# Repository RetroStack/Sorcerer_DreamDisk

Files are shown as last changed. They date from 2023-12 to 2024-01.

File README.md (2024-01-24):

# Exidy Sorcerer DreamDisk - Disk Controller

A Disk Controller for the Exidy Sorcerer, based on the Disk Controller by DreamCards.

Requires SCUAMON3.4 Monitor ROMS with Dreamdisk FDC support installed in Sorcerer for Cold Booting Dreamdisk.

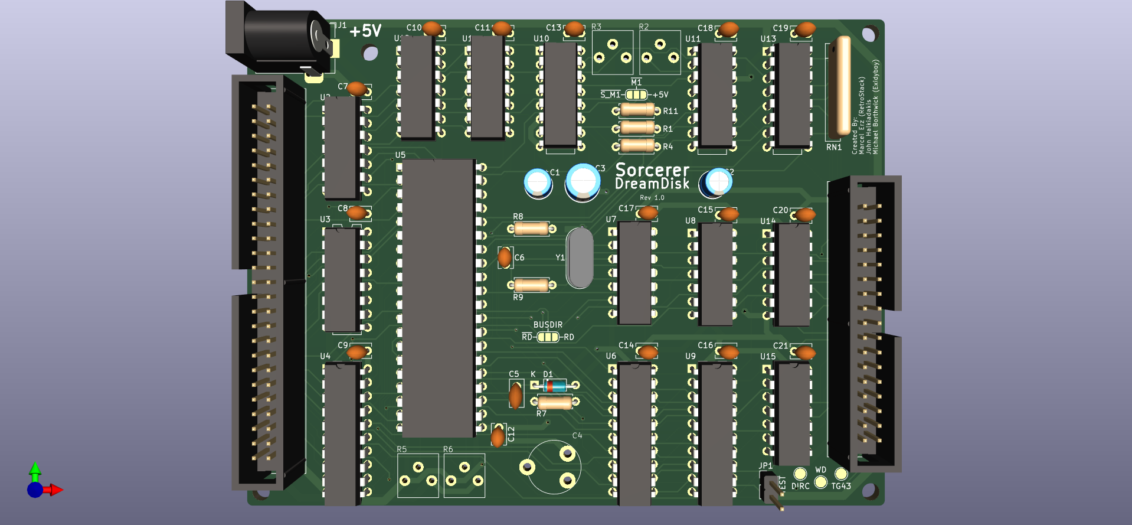
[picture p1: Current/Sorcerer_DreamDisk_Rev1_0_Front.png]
Sorcerer DreamDisk Front

[Schematics](Current/Sorcerer_DreamDisk_Rev1_0_Schematics.pdf)

## Gerber Files
- [PCBWay](Current/Sorcerer_DreamDisk_Rev1_0_Gerber_PCBWay.zip)
- [JLCPCB](Current/Sorcerer_DreamDisk_Rev1_0_Gerber_JLCPCB.zip)

## Attribution
- Marcel Erz (RetroStack)
- John Halkiadakis
- Michael Borthwick (Exidyboy)

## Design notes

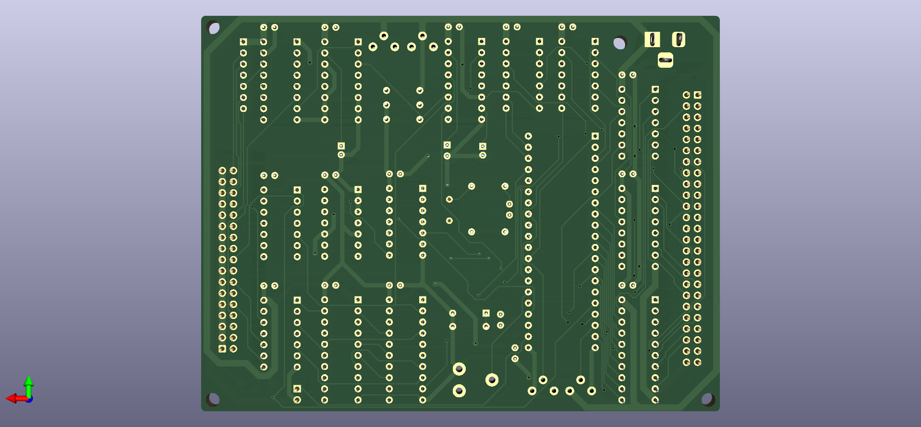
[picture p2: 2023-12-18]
Current/Sorcerer_DreamDisk_Rev1_0_Back.png

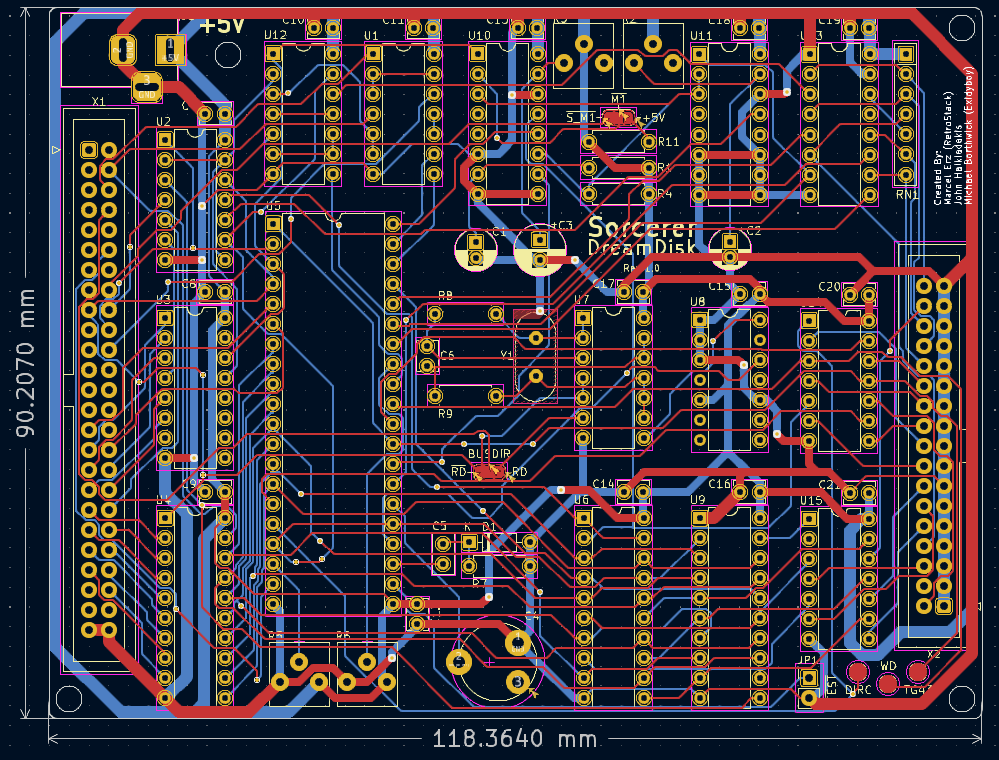
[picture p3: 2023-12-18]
Current/Sorcerer_DreamDisk_Rev1_0_PCB.png

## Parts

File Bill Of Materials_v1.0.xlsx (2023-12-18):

Mouser No | Mfr. No | Manufacturer | PCB Layout | Description | Order Qty. | Price (AUD) | Ext.: (AUD)
810-FG14X7R1H224KNT0 | FG14X7R1H224KNT00 | TDK | C5 | Multilayer Ceramic Capacitors MLCC - Leaded RAD 50V 0.22uF X7R 10% LS:2.5mm | 1 | $0.47 | $0.47
594-K104K10X7RF53H5 | K104K10X7RF53H5 | Vishay | C6, C8-C21 | Multilayer Ceramic Capacitors MLCC - Leaded 0.1uF 50V 10% X7R 5mm LS | 16 | $0.167 | $2.67
603-MFR-25FBF52-4K7 | MFR-25FBF52-4K7 | YAGEO | R11 | Metal Film Resistors - Through Hole 4.7K OHM 1/4W 1% | 1 | $0.162 | $0.16
603-MFR-25FRF52-470R | MFR-25FRF52-470R | YAGEO | R8, R9 | Metal Film Resistors - Through Hole 470 OHM 1/4W 1% | 2 | $0.162 | $0.32
603-MFR-25FRE52-1K | MFR-25FRE52-1K | YAGEO | R1, R7 | Metal Film Resistors - Through Hole 1Kohm 1% 1/4W Metal Film Resistor | 2 | $0.162 | $0.32
603-MFR-25FRF5210K | MFR-25FRF52-10K | YAGEO | R4 | Metal Film Resistors - Through Hole 10 kOhms 250 mW 1% 100 PPM / C | 1 | $0.162 | $0.16
652-4607X-1LF-4.7K | 4607X-101-472LF | Bourns | RN1 | Resistor Networks & Arrays 7pins 4.7Kohms Bussed | 1 | $0.81 | $0.81
595-SN74LS02N | SN74LS02N | Texas Instruments | U1 | Logic Gates Quad 2-Input | 1 | $0.891 | $0.89
595-SN74LS32N | SN74LS32N | Texas Instruments | U2 | Logic Gates Quad 2-Input | 1 | $0.907 | $0.91
595-SN74LS138N | SN74LS138N | Texas Instruments | U3 | Encoders, Decoders, Multiplexers & Demultiplexers Line Decoder | 1 | $1.13 | $1.13
595-SN74LS245N | SN74LS245N | Texas Instruments | U4 | Bus Transceivers Octal Bus | 1 | $2.01 | $2.01
595-SN74LS244N | SN74LS244N | Texas Instruments | U6 | Buffers & Line Drivers Tri-State Octal | 1 | $1.88 | $1.88
595-SN74LS00N | SN74LS00N | Texas Instruments | U7, U12 | Logic Gates Quad 2-In Pos NAND | 2 | $0.923 | $1.85
512-1N914TR | 1N914TR | onsemi | D1 | Diodes - General Purpose, Power, Switching Hi Conductance Fast | 1 | $0.162 | $0.16
649-67998-400HLF | 67998-400HLF | Amphenol | JP1 TEST | Headers & Wire Housings .100CC STR HEADER | 1 | $0.162 | $0.16
710-860020672005 | 860020672005 | Wurth Elektronik | C1 | Aluminium Electrolytic Capacitors - Radial Leaded WCAP-ATG5 1uF 50V 20% Radial | 1 | $0.162 | $0.16
710-860020472006 | 860020472006 | Wurth Elektronik | C2 | Aluminium Electrolytic Capacitors - Radial Leaded WCAP-ATG5 47uF 25V 20% Radial | 1 | $0.162 | $0.16
710-860010273009 | 860010273009 | Wurth Elektronik | C3 | Aluminium Electrolytic Capacitors - Radial Leaded WCAP-ATG8 220uF 10V 20% Radial | 1 | $0.243 | $0.24
595-SN74LS374N | SN74LS374N | Texas Instruments | U9 | Flip-Flops Octal | 1 | $2.01 | $2.01
595-SN74LS123N | SN74LS123N | Texas Instruments | U10, U11 | Monostable Multi-vibrator Dual Mono | 2 | $1.30 | $2.60
595-SN74LS367AN | SN74LS367AN | Texas Instruments | U13 | Buffers & Line Drivers Hex Bus Drivers With 3-State Outputs | 1 | $2.33 | $2.33
595-SN74LS06N | SN74LS06N | Texas Instruments | U14 | Buffers & Line Drivers Hex inverter Buffer/ Driver | 1 | $1.49 | $1.49
571-5103308-7 | 5103308-7 | TE Connectivity | X2 | Headers & Wire Housings 34P HEADER | 1 | $6.04 | $6.04
571-1-5103308-0 | 1-5103308-0 | TE Connectivity | X1 | Headers & Wire Housings 50P HEADER SP 15DP | 1 | $6.66 | $6.66
652-3306P-1-503 | 3306P-1-503 | Bourns | R2 ,R5 | Trimmer Resistors - Through Hole 50K 25% 6mm Single Turn | 2 | $0.713 | $1.43
652-3306P-1-502 | 3306P-1-502 | Bourns | R6 (ONLY for 8") | Trimmer Resistors - Through Hole 5K 25% 6mm Single Turn | 1 | $0.761 | $0.76
652-3306P-1-104 | 3306P-1-104 | Bourns | R3 | Trimmer Resistors - Through Hole 100K 25% 6mm Single Turn | 1 | $0.794 | $0.79
73-XT49S400-20 | XT9S20ANA4M | Vishay | Y1 | Crystals 4MHz 20pF | 1 | $0.778 | $0.78
474-PRT-10811 | PRT-10811 | SparkFun Electronics | J1 | SparkFun Accessories DC Barrel Jack Adapter - Breadboard Compatible | 1 | $1.54 | $1.54
595-SN74LS07N | SN74LS07N | Texas Instruments | U15 | Buffers & Line Drivers Hex W/ OC HV Out | 1 | $1.15 | $1.15
594-2222-808-32659 | BFC280832659 | Vishay | C4 (VCO ADJ) | Trimmer/Variable Capacitors TRIMMER CAPACITOR (5.5 pF to 65 pF) | 1 | $9.98 | $9.98
595-SN74LS93N | SN74LS93N | Texas Instruments | U8 | Counter ICs 4bit Binary | 1 | $4.92 | $4.92
WD2793 | N/A | N/A | U5 | Western Digital 2793 Floppy Disk Controller

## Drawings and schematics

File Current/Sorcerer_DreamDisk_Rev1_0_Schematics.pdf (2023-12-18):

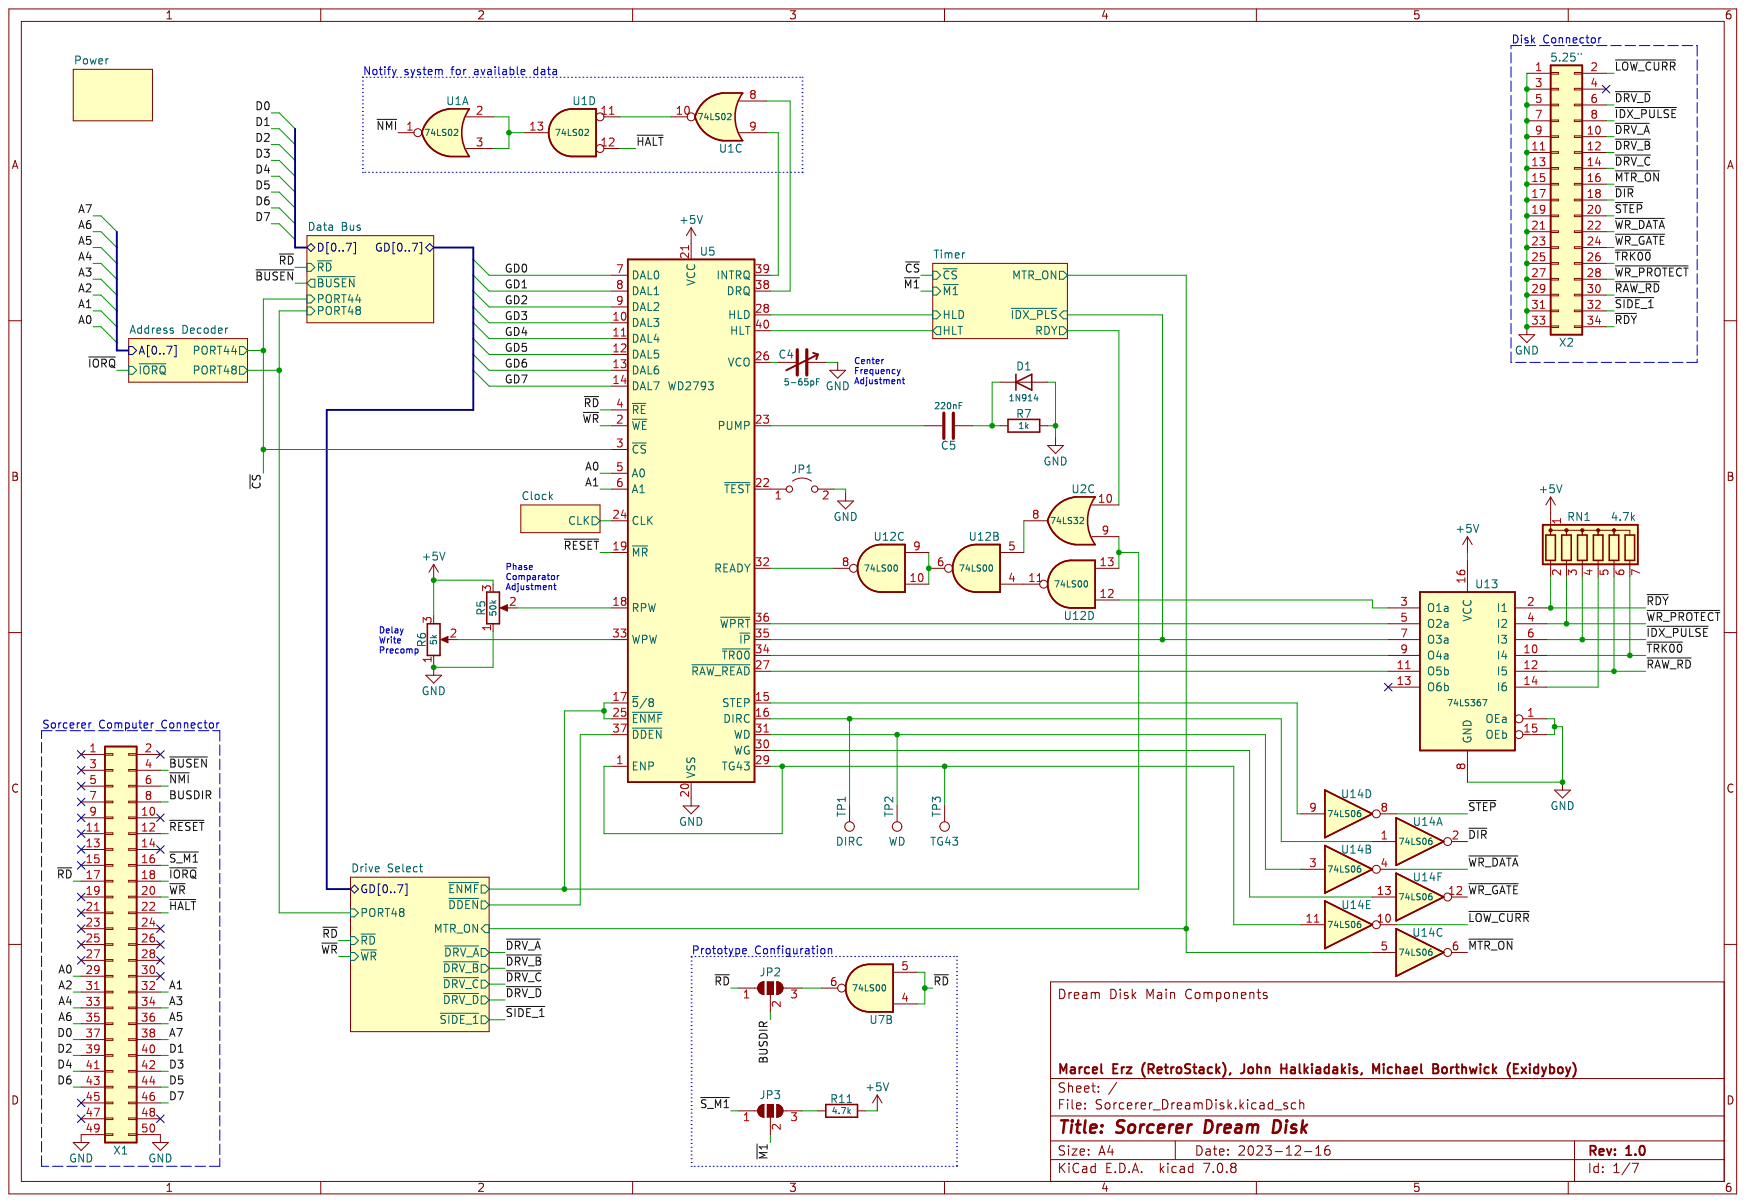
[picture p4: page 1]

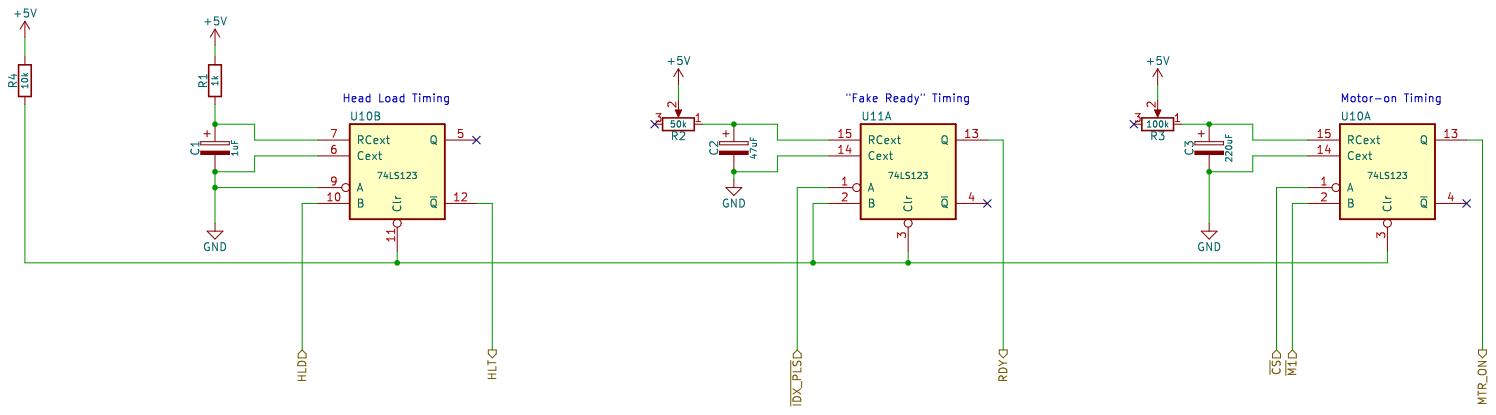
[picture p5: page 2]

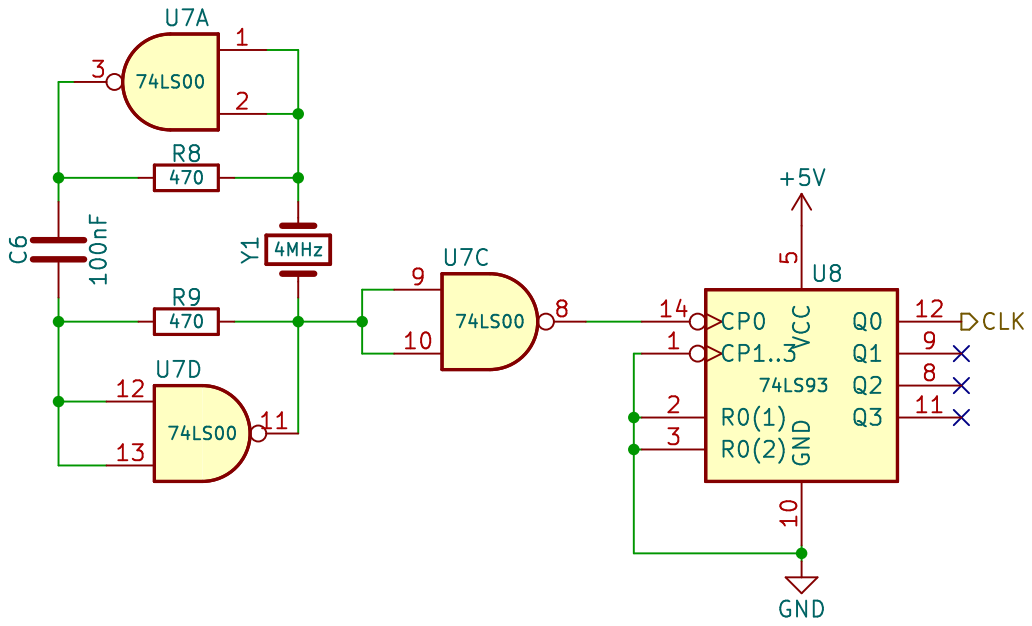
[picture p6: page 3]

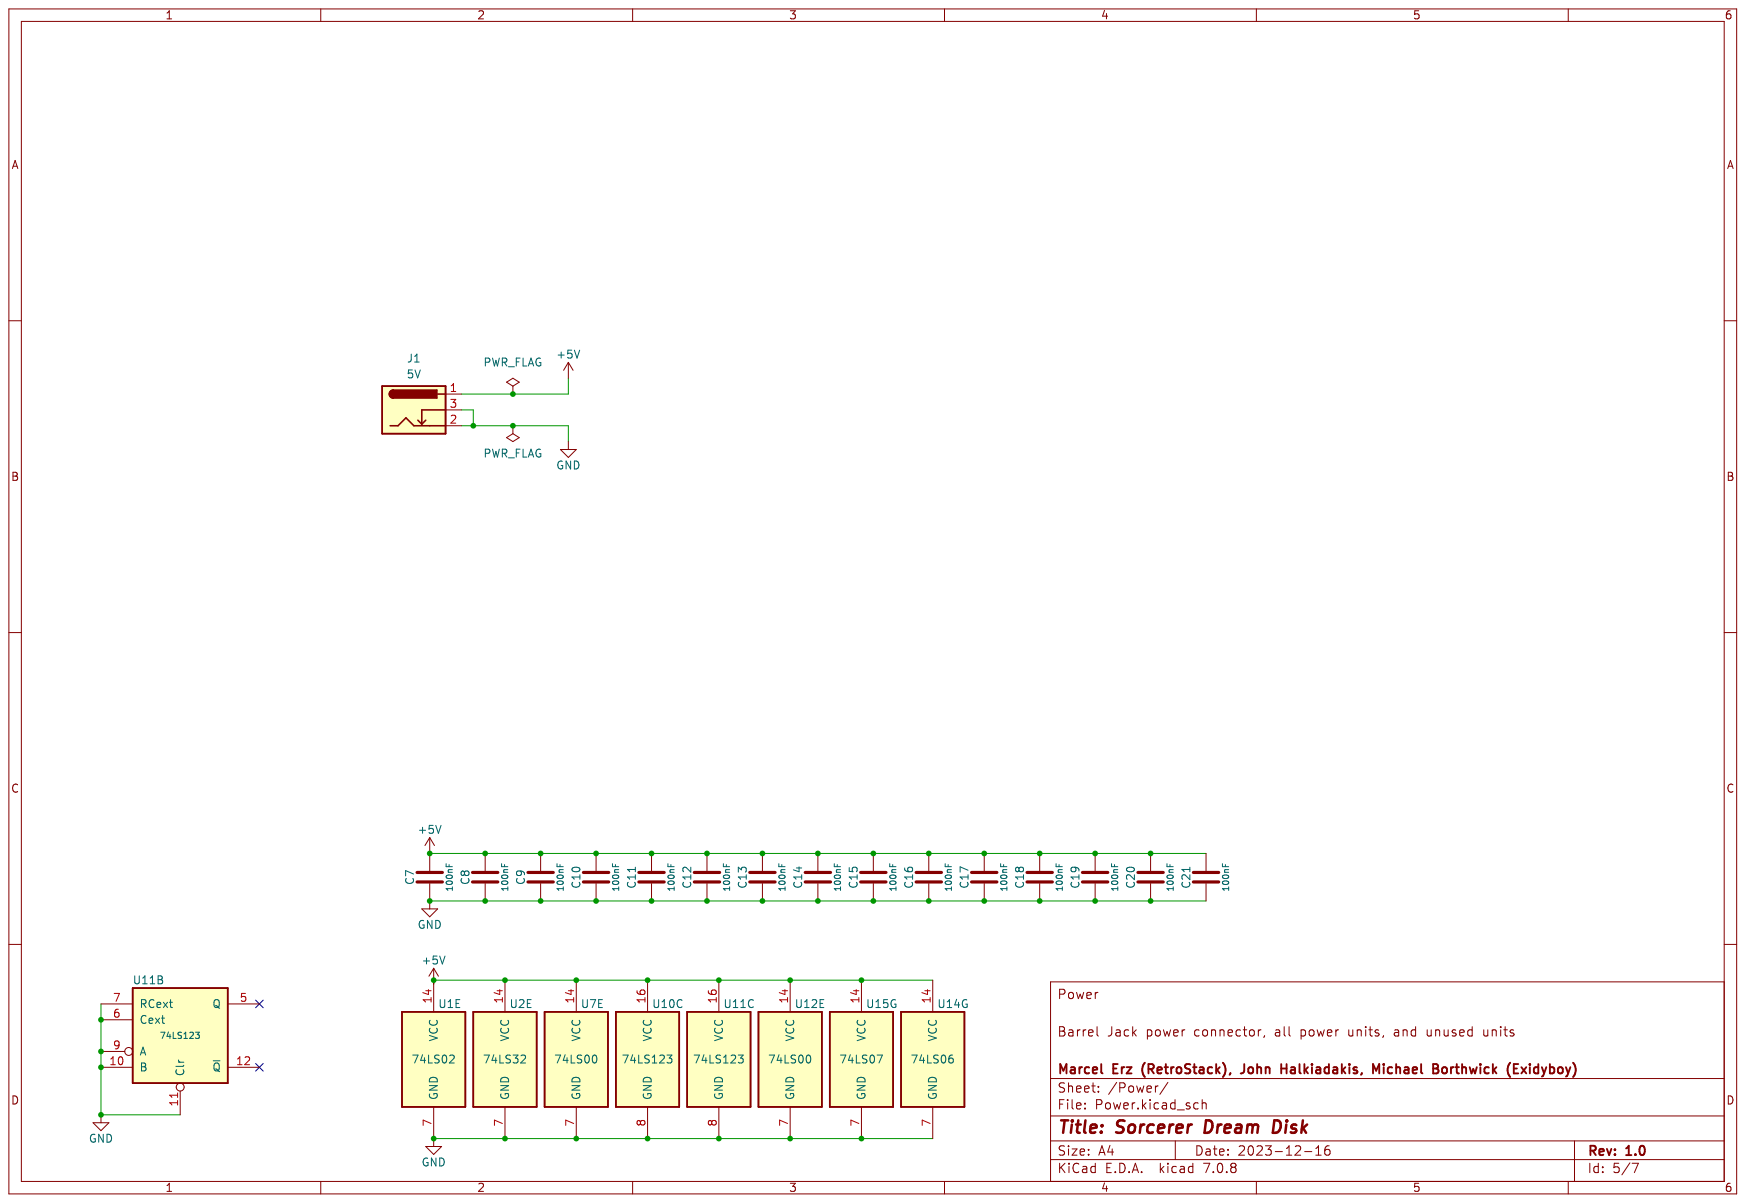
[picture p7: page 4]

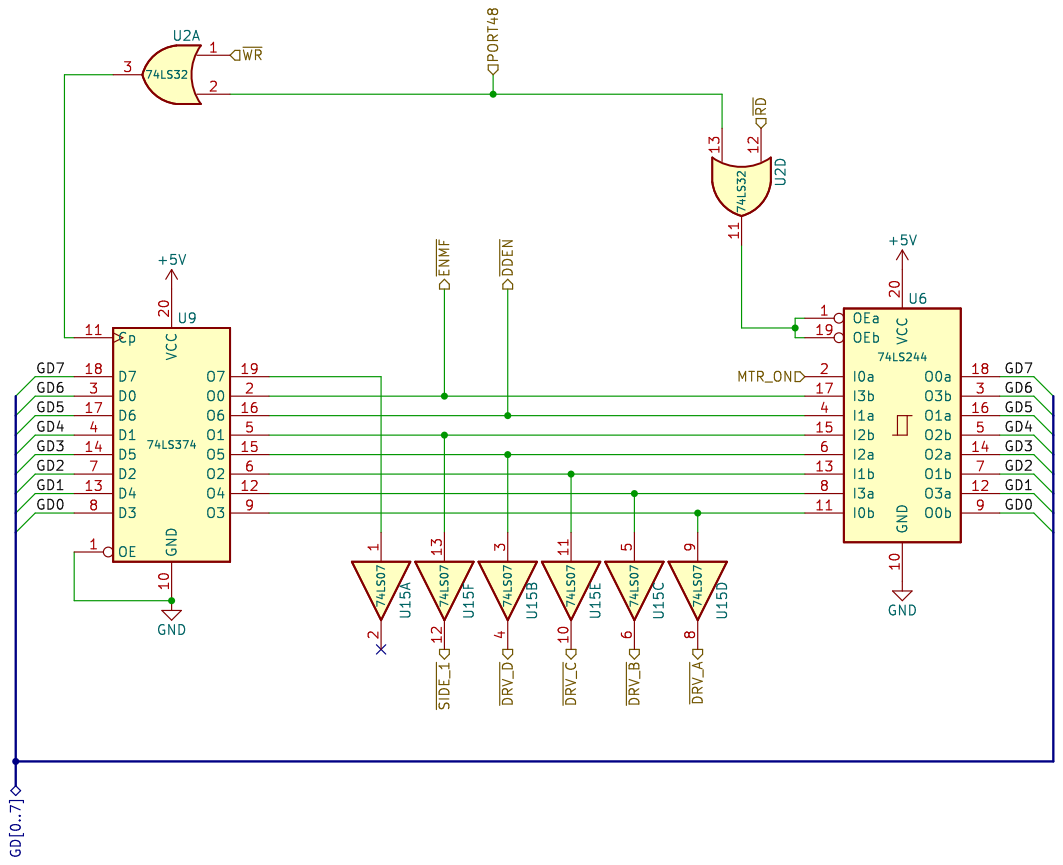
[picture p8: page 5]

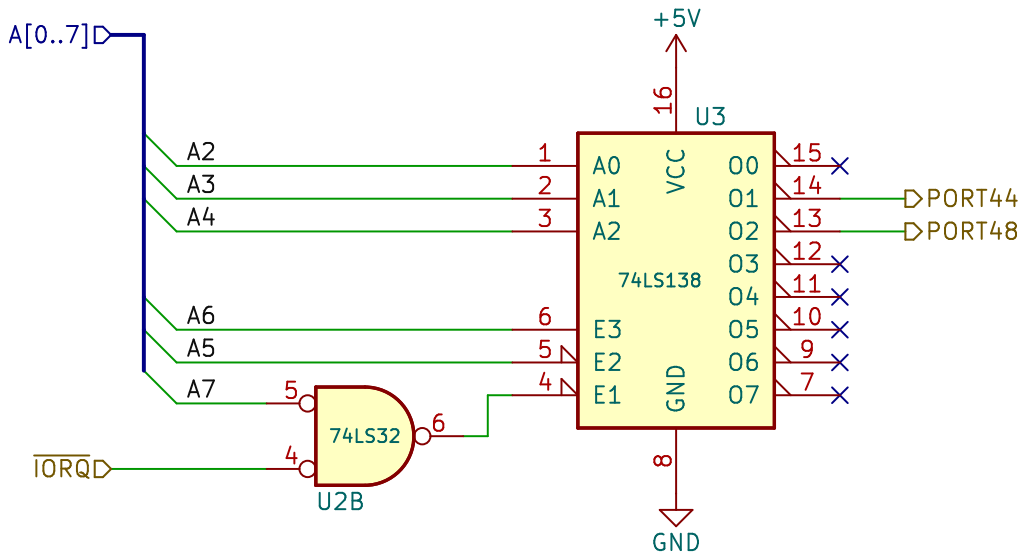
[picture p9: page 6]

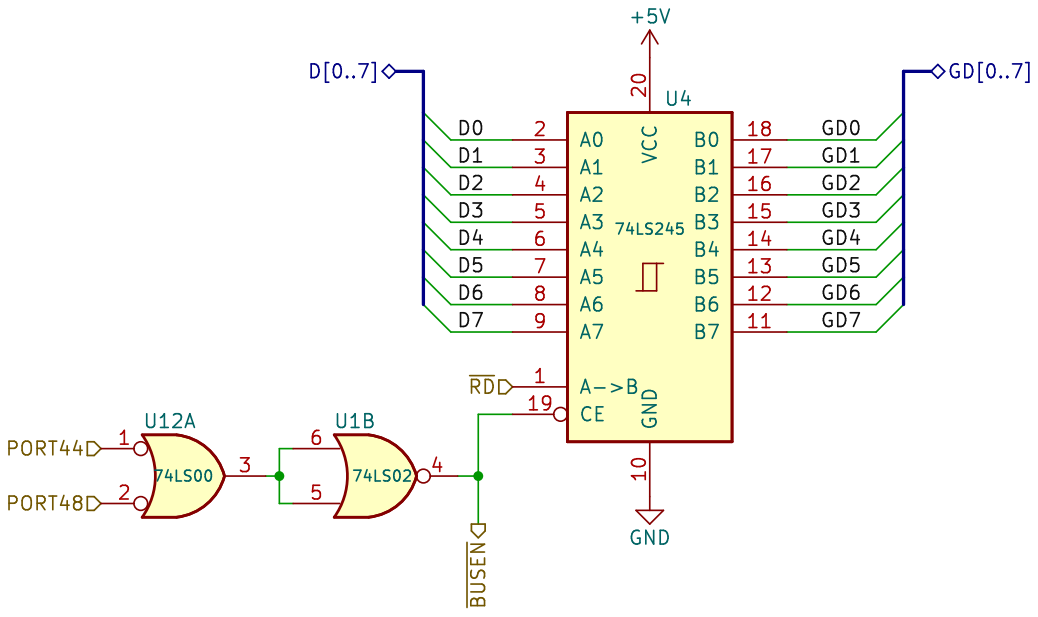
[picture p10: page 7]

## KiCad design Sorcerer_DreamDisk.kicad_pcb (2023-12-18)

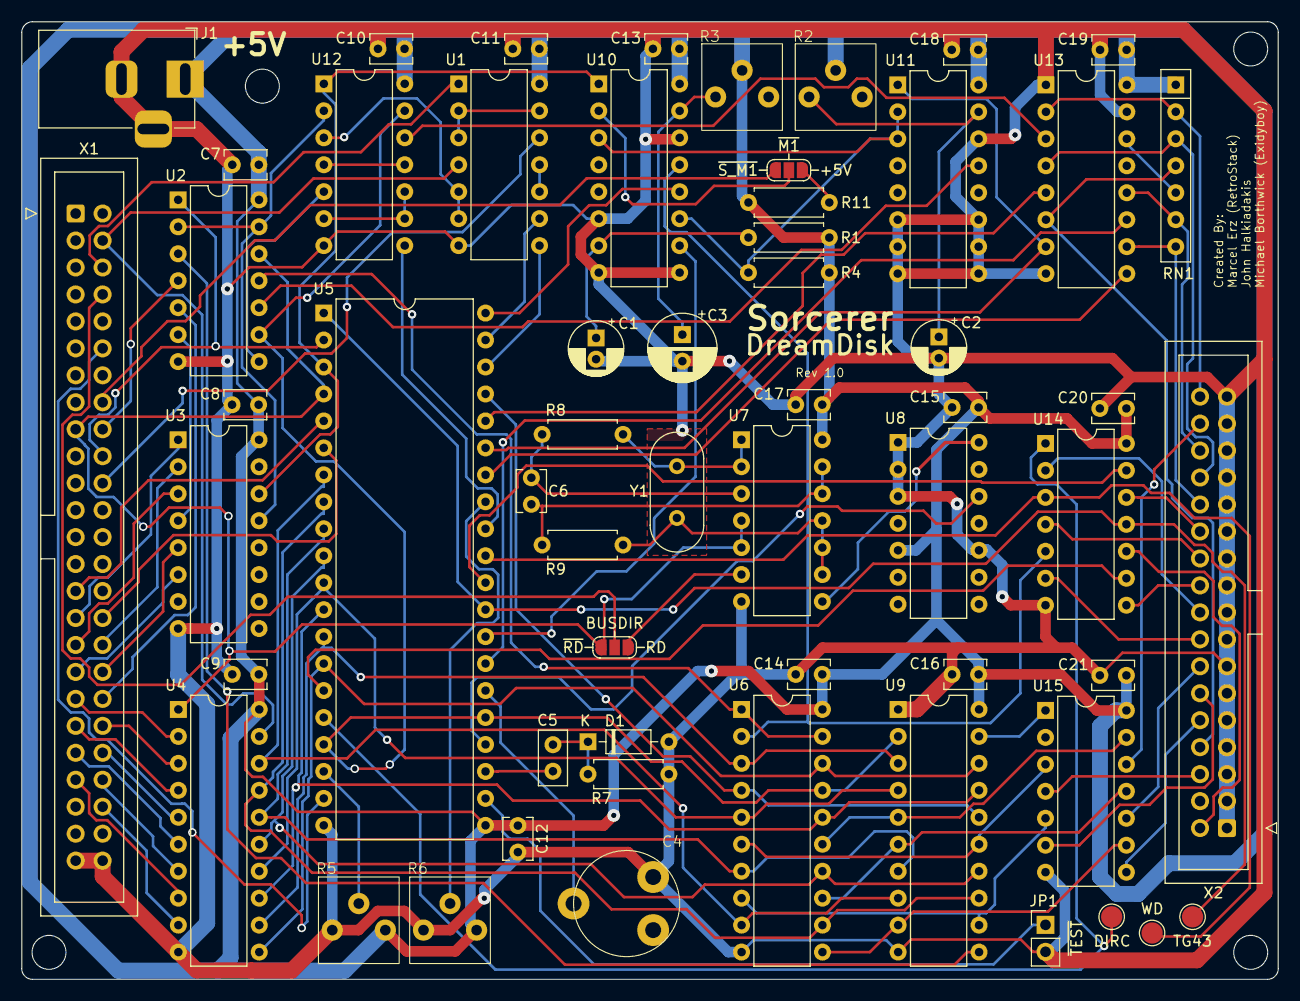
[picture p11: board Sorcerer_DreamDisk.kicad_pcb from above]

Board: 2 copper layers, 118.4 x 90.2 mm, 58 parts (0 on the bottom side), 107 nets.

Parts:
C1: 1uF; CP_Radial_D5.0mm_P2.00mm
C2: 47uF; CP_Radial_D5.0mm_P2.00mm
C3: 220uF; CP_Radial_D6.3mm_P2.50mm
C4: 5-65pF; C_Trim (BFC2 808 32659)
C5: 220nF; C_Disc_D5.0mm_W2.5mm_P2.50mm
C6, C7, C8, C9, C10, C11, C12, C13, C14, C15, C16, C17, C18, C19, C20, C21: 100nF; C_Disc_D3.8mm_W2.6mm_P2.50mm
D1: 1N914; D_DO-35_SOD27_P7.62mm_Horizontal
J1: 5V; BarrelJack_Horizontal
JP1: Jumper_2_Open; PinHeader_1x02_P2.54mm_Vertical
JP2, JP3: SolderJumper_3_Open; SolderJumper-3_P1.3mm_Open_RoundedPad1.0x1.5mm_NumberLabels
R1, R7: 1k; R_Axial_DIN0207_L6.3mm_D2.5mm_P7.62mm_Horizontal
R2, R5: 50k; R_Pot (Bourns 3306P)
R3: 100k; R_Pot (Bourns 3306P)
R4: 10k; R_Axial_DIN0207_L6.3mm_D2.5mm_P7.62mm_Horizontal
R6: 5k; R_Pot (Bourns 3306P)
R8, R9: 470; R_Axial_DIN0207_L6.3mm_D2.5mm_P7.62mm_Horizontal
R11: 4.7k; R_Axial_DIN0207_L6.3mm_D2.5mm_P7.62mm_Horizontal
RN1: 4.7k; R_Array_SIP7
TP1: DIRC; TestPoint_Pad_D2.0mm
TP2: WD; TestPoint_Pad_D2.0mm
TP3: TG43; TestPoint_Pad_D2.0mm
U1: 74LS02; DIP-14_W7.62mm
U2: 74LS32; DIP-14_W7.62mm
U3: 74LS138; DIP-16_W7.62mm
U4: 74LS245; DIP-20_W7.62mm
U5: WD2793; DIP-40_W15.24mm
U6: 74LS244; DIP-20_W7.62mm
U7, U12: 74LS00; DIP-14_W7.62mm
U8: 74LS93; DIP-14_W7.62mm
U9: 74LS374; DIP-20_W7.62mm
U10, U11: 74LS123; DIP-16_W7.62mm
U13: 74LS367; DIP-16_W7.62mm
U14: 74LS06; DIP-14_W7.62mm
U15: 74LS07; DIP-14_W7.62mm
X1: To_Computer; IDC-Header_2x25_P2.54mm_Vertical
X2: 5.25"; IDC-Header_2x17_P2.54mm_Vertical
Y1: 4MHz; Crystal_HC49-U_Vertical

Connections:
+5V: C7.2, C8.2, C9.2, C10.2, C11.2, C12.2, C13.2, C14.2, C15.2, C16.2, C17.2, C18.2, C19.2, C20.2, C21.2, J1.1, R1.1, R2.2, R3.2, R4.1, R5.3, R6.3, R11.1, RN1.1 (common), U1.14 (VCC), U2.14 (VCC), U3.16 (VCC), U4.20 (VCC), U5.21 (VCC), U6.20 (VCC), U7.14 (VCC), U8.5 (VCC), U9.20 (VCC), U10.16 (VCC), U11.16 (VCC), U12.14 (VCC), U13.16 (VCC), U14.14 (VCC), U15.14 (VCC)
/Address Decoder/A0: U5.5 (A0), X1.29
/Address Decoder/A1: U5.6 (A1), X1.32
/Address Decoder/A2: U3.1 (A0), X1.31
/Address Decoder/A3: U3.2 (A1), X1.34
/Address Decoder/A4: U3.3 (A2), X1.33
/Address Decoder/A5: U3.5 (E2), X1.36
/Address Decoder/A6: U3.6 (E3), X1.35
/Address Decoder/A7: U2.5, X1.38
/Address Decoder/PORT48: U2.2, U2.13, U3.13 (O2), U12.2
/BUSDIR: JP2.2 (C), X1.8
/Clock/CLK: U5.24 (CLK), U8.12 (Q0)
/Data Bus/D0: U4.2 (A0), X1.37
/Data Bus/D1: U4.3 (A1), X1.40
/Data Bus/D2: U4.4 (A2), X1.39
/Data Bus/D3: U4.5 (A3), X1.42
/Data Bus/D4: U4.6 (A4), X1.41
/Data Bus/D5: U4.7 (A5), X1.44
/Data Bus/D6: U4.8 (A6), X1.43
/Data Bus/D7: U4.9 (A7), X1.46
/Data Bus/GD0: U4.18 (B0), U5.7 (DAL0), U6.9 (O0b), U9.8 (D3)
/Data Bus/GD1: U4.17 (B1), U5.8 (DAL1), U6.12 (O3a), U9.13 (D4)
/Data Bus/GD2: U4.16 (B2), U5.9 (DAL2), U6.7 (O1b), U9.7 (D2)
/Data Bus/GD3: U4.15 (B3), U5.10 (DAL3), U6.14 (O2a), U9.14 (D5)
/Data Bus/GD4: U4.14 (B4), U5.11 (DAL4), U6.5 (O2b), U9.4 (D1)
/Data Bus/GD5: U4.13 (B5), U5.12 (DAL5), U6.16 (O1a), U9.17 (D6)
/Data Bus/GD6: U4.12 (B6), U5.13 (DAL6), U6.3 (O3b), U9.3 (D0)
/Data Bus/GD7: U4.11 (B7), U5.14 (DAL7), U6.18 (O0a), U9.18 (D7)
/Drive Select/MTR_ON: U6.2 (I0a), U10.13 (Q), U14.5
/Drive Select/~DDEN: U5.37 (~DDEN), U6.4 (I1a), U9.16 (O6)
/Drive Select/~ENMF: U2.9, U5.17 (~5/8), U5.25 (~ENMF), U6.17 (I3b), U9.2 (O0), U12.13
/Timer/HLD: U5.28 (HLD), U10.10 (B)
/Timer/HLT: U5.40 (HLT), U10.12 (~Q)
/Timer/RDY: U2.10, U11.13 (Q)
/Timer/~IDX_PLS: U5.35 (~IP), U11.1 (A), U13.7 (O3a)
/~BUSEN: U1.4, U4.19 (CE), X1.4
/~CS: U3.14 (O1), U5.3 (~CS), U10.1 (A), U12.1
/~DIR: U14.2, X2.18
/~DRV_A: U15.8, X2.10
/~DRV_B: U15.6, X2.12
/~DRV_C: U15.10, X2.14
/~DRV_D: U15.4, X2.6
/~HALT: U1.12, X1.22
/~IDX_PULSE: RN1.4 (R3), U13.6 (I3), X2.8
/~IORQ: U2.4, X1.18
/~LOW_CURR: U14.10, X2.2
/~M1: JP3.2 (C), U10.2 (B)
/~MTR_ON: U14.6, X2.16
/~NMI: U1.1, X1.6
/~RAW_RD: RN1.6 (R5), U13.12 (I5), X2.30
/~RDY: RN1.2 (R1), U13.2 (I1), X2.34
/~RD: JP2.1 (A), U2.12, U4.1 (A->B), U5.4 (~RE), U7.4, U7.5, X1.17
/~RESET: U5.19 (~MR), X1.12
/~SIDE_1: U15.12, X2.32
/~STEP: U14.8, X2.20
/~S_M1: JP3.1 (A), X1.16
/~TRK00: RN1.7 (R6), U13.10 (I4), X2.26
/~WR_DATA: U14.4, X2.22
/~WR_GATE: U14.12, X2.24
/~WR_PROTECT: RN1.3 (R2), U13.4 (I2), X2.28
/~WR: U2.1, U5.2 (~WE), X1.20
GND: C1.2, C2.2, C3.2, C4.1, C7.1, C8.1, C9.1, C10.1, C11.1, C12.1, C13.1, C14.1, C15.1, C16.1, C17.1, C18.1, C19.1, C20.1, C21.1, D1.2 (A), J1.2, J1.3, JP1.2 (B), R5.1, R6.1, R7.2, U1.7 (GND), U2.7 (GND), U3.8 (GND), U4.10 (GND), U5.20 (VSS), U6.10 (GND), U7.7 (GND), U8.1 (CP1..3), U8.2 (R0(1)), U8.3 (R0(2)), U8.10 (GND), U9.1 (OE), U9.10 (GND), U10.6 (Cext), U10.8 (GND), U10.9 (A), U10.14 (Cext), U11.6 (Cext), U11.7 (RCext), U11.8 (GND), U11.9 (A), U11.10 (B), U11.11 (Clr), U11.14 (Cext), U12.7 (GND), U13.1 (OEa), U13.8 (GND), U13.15 (OEb), U14.7 (GND), U15.7 (GND), X1.49, X1.50, X2.1, X2.3, X2.5, X2.7, X2.9, X2.11, X2.13, X2.15, X2.17, X2.19, X2.21, X2.23, X2.25, X2.27, X2.29, X2.31, X2.33
unnamed: C6.1, R8.2, U7.3
unnamed: C6.2, R9.2, U7.12, U7.13
unnamed: C5.2, D1.1 (K), R7.1
unnamed: JP1.1 (A), U5.22 (~TEST)
unnamed: JP2.3 (B), U7.6
unnamed: JP3.3 (B), R11.2
unnamed: R8.1, U7.1, U7.2, Y1.2
unnamed: R9.1, U7.9, U7.10, U7.11, Y1.1
unnamed: RN1.5 (R4), U13.14 (I6)
unnamed: U1.5, U1.6, U12.3
unnamed: U1.10, U1.11
unnamed: U1.2, U1.3, U1.13
unnamed: U2.6, U3.4 (E1)
unnamed: TP1.1, U5.16 (DIRC), U14.1
unnamed: U1.8, U5.38 (DRQ)
unnamed: TP3.1, U5.1 (ENP), U5.29 (TG43), U14.11
unnamed: U1.9, U5.39 (INTRQ)
unnamed: C5.1, U5.23 (PUMP)
unnamed: U5.32 (READY), U12.8
unnamed: R5.2, U5.18 (RPW)
unnamed: U5.15 (STEP), U14.9
unnamed: C4.2, U5.26 (VCO)
unnamed: TP2.1, U5.31 (WD), U14.3
unnamed: U5.30 (WG), U14.13
unnamed: R6.2, U5.33 (WPW)
unnamed: U6.11 (I0b), U9.9 (O3), U15.9
unnamed: U6.13 (I1b), U9.6 (O2), U15.11
unnamed: U6.6 (I2a), U9.15 (O5), U15.3
unnamed: U6.15 (I2b), U9.5 (O1), U15.13
unnamed: U6.8 (I3a), U9.12 (O4), U15.5
unnamed: U2.11, U6.1 (OEa), U6.19 (OEb)
unnamed: U7.8, U8.14 (CP0)
unnamed: U2.3, U9.11 (Cp)
unnamed: U9.19 (O7), U15.1
unnamed: R4.2, U10.3 (Clr), U10.11 (Clr), U11.2 (B), U11.3 (Clr)
unnamed: C3.1, R3.1, U10.15 (RCext)
unnamed: C1.1, R1.2, U10.7 (RCext)
unnamed: C2.1, R2.1, U11.15 (RCext)
unnamed: U2.8, U12.5
unnamed: U12.6, U12.9, U12.10
unnamed: U12.4, U12.11
unnamed: U12.12, U13.3 (O1a)
unnamed: U5.36 (~WPRT), U13.5 (O2a)
unnamed: U5.34 (~TR00), U13.9 (O4a)
unnamed: U5.27 (~RAW_READ), U13.11 (O5b)

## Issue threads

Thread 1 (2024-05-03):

Dream disc for Microbee with 8" drive support

pocoaust, 2024-05-03:
G'day,

I was going through the process of trying to recreate the dreamdisk for microbee when I came across your Project.  Would it be as simple as changing the 50 way interface wiring to get it to work with the bee, and adding the 50 pin 8" interface?  Looking at the RM001 schematics you have added BusDir and BusEn...    is this from the later version?

Did you also manage to actually get a real original Board?

Thanks
Paul

vk3yp, 2024-10-27:
Hi Paul,

The Dreamdisk FDC is based on the RM001 per the schematics from the original manual. We don't have an original RM001 FDC board - so everything was reverse engineered from the schematics only.

The circuit was modified for Sorcerer 50 PIN BUS pinout (i.e. not requiring the external original dreamdisk adapter PCB for the Sorcerer).

If you build an external PCB of your own design, you can remap the 50 PIN BUS pinouts back to Microbee. The bus pinout mapping is described in the original Dreamdisk Sorcerer manual.

We deleted the 8" disk drive header from the PCB to simplify and have only a 5.25" drive interface.
We also added the Busdir and BusEn pcb jumpers for testing and these can be removed from a future revision PCB.

Have a look at the files at the exidy sorcerer forums on how to setup and test the PCB including the jumpers.

https://www.exidysorcerer.net/
https://filebrowser.exidysorcerer.net/

Without any changes to the current PCB - You can add external PCB (your design) to remap the 50 way bus signals back to Microbee and also you can use one of the many commercially available (pre-built) 8" to 5.25" PCB adapters.
Like this one.
https://texelec.com/product/8-inch-floppy-adapter/

We hope to have an updated Dreamdisk PCB with both Sorcerer and Microbee 50 way bus headers on the same PCB (and some minor updates such as removing the Busdir and BusEn jumpers). @marcelerz

John

pocoaust, 2024-10-27:
Thanks for keeping me informed....

I have a microbee, but not a sorcerer, I will try to find one as well.

Thanks

On Sun, 27 Oct 2024, 8:40 pm John Halkiadakis, ***@***.***>
wrote:

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

marcelerz, 2025-05-12:
A new version was just released that does support the MicroBee now. However, we still don't have a 8" disk support.

vk3yp, 2025-05-12:
8" Floppy support can be supported via an 8" 50 way to 5.25" 34 way adapter board.
Like this one:
https://texelec.com/product/8-inch-floppy-adapter/

Closed 2025-05-12.

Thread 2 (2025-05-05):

2Mhz Clock Circuit Fix (Clean 2Mhz Clock signal)

vk3yp, 2025-05-05:
This fix provides a clean 2Mhz clock signal to the CLK input (PIN 24) of the WD2793.

-	You need to add a 470PF (ceramic disc capacitor) between PIN 14 (CLK A INPUT) and PIN 1 (GND) ON IC U8 (74LS93) on the bottom of the PCB or you can add it to the legs of the 74LS93 IC (from the top of the PCB).

Photo image shows a 0603 package (470PF Surface Mount Capacitor) but a normal 470PF disk ceramic capacitor is fine.

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

marcelerz, 2025-05-12:
To clarify, this is for Rev 1.0 only. Rev 1.1 has this already fixed.

Closed 2025-05-05.
